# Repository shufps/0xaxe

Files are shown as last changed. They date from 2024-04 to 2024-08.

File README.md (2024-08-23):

**WARNING**: The 0xAxe is the *end level boss for Pros*. It's hard to get it working properly. The main reason is the powering scheme that uses 4 different voltage domain. It's difficult to get it into balance properly and needs very good and uniform cooling. The device works but can be super frustrating until it really is mining as it should. 

# 0xaxe

0xAxe is a 16-ASIC-BM1366 Miner based on the [QAxe](https://github.com/shufps/qaxe)



**rev1**: not tested</br>
**rev1.1**: working but needs some manual fixes</br>
**rev1.2**: should be working without fixes, but not tested yet.</br>

0xAxe is working (see screenshot at the end of the page to get an impression what to expect) 🥳

**note**: The 0xAxe is not a stand-alone device because it only supports USB but it can be run connected to a Raspberry Pi without problems. Also multiple devices can be connected to a single Pi. 

ASICs
=====

The 0xAxe uses 16 ASICs of type BM1366



Compilation (Bootloader or CMSIS-DAP)
======================================

```bash
# install curl
sudo apt install curl

# install rust
curl --proto '=https' --tlsv1.2 https://sh.rustup.rs -sSf | sh

# add to ~/.bash.rc (afterwards, opening a new terminal is needed)
echo 'source "$HOME/.cargo/env"' >> ~/.bashrc

# clone repository
git clone https://github.com/shufps/0xaxe

# clone submodules
cd 0xaxe
git submodule init
git submodule update

# add rust target for STM32L0 variants
rustup target add thumbv6m-none-eabi

# build firmware for L072
cd firmware/fw-L072KZ
./build.sh
```

Installation via USB Bootloader on board with `BOOT` button
===========================================================
The STM32L072CB variant has an integrated DFU Bootloader that starts when pressing the `BOOT` button during reset.

Afterwards the firmware can be flashed via `dfu-utils`:

```bash
# install cargo-binutils and llvm tools
cargo install cargo-binutils
rustup component add llvm-tools-preview

# create the firmware.bin
DEFMT_LOG=info cargo objcopy --release --bin qaxe -- -O binary 0xaxe.bin

# install dfu-utils
sudo apt-get install dfu-util

now start the stm32 in DFU mode by pressing `boot` 

# after booting, list the devices
dfu-util --list

# flash the binary
dfu-util -a 0 -s 0x08000000:leave -D 0xaxe.bin
```

Installation via CMSIS-DAP Programmer
=====================================

**note**: Using CMSIS-DAP and PicoProbe is only interesting for developers trying to alter the firmware.

As programming/debug adapter the Picoprobe firmware running on a Raspi Pico works best: <br>
https://github.com/rp-rs/rp2040-project-template/blob/main/debug_probes.md / https://github.com/raspberrypi/picoprobe/releases/tag/picoprobe-cmsis-v1.0.3
<br>
<br>
There also is a little board with only 3 parts that gives a nice low-cost solution to flash the Qaxe:<br>
https://github.com/shufps/raspi-pico-dap

On `rev3` there should be the option to boot the stm32 (by pressing the `boot`-button on reset) into DFU-Bootloader mode what makes flashing via USB and without CMSIS-DAP programmer possible.

## Flashing

After the source was compiled it is flashed by:

```bash
# build firmware for L072
cd firmware/fw-L072KZ
# run firmware (this also flashes it to the stm32)
./run.sh
```

Mining Client
=============



Stratum Mining Client:<br>
https://github.com/shufps/piaxe-miner

Misc
====
If you like this project and want to support future work, feel free to donate to: `bc1q29hp4fqtks2wzpmfwtpac64fnr8ujw2nvnra04`

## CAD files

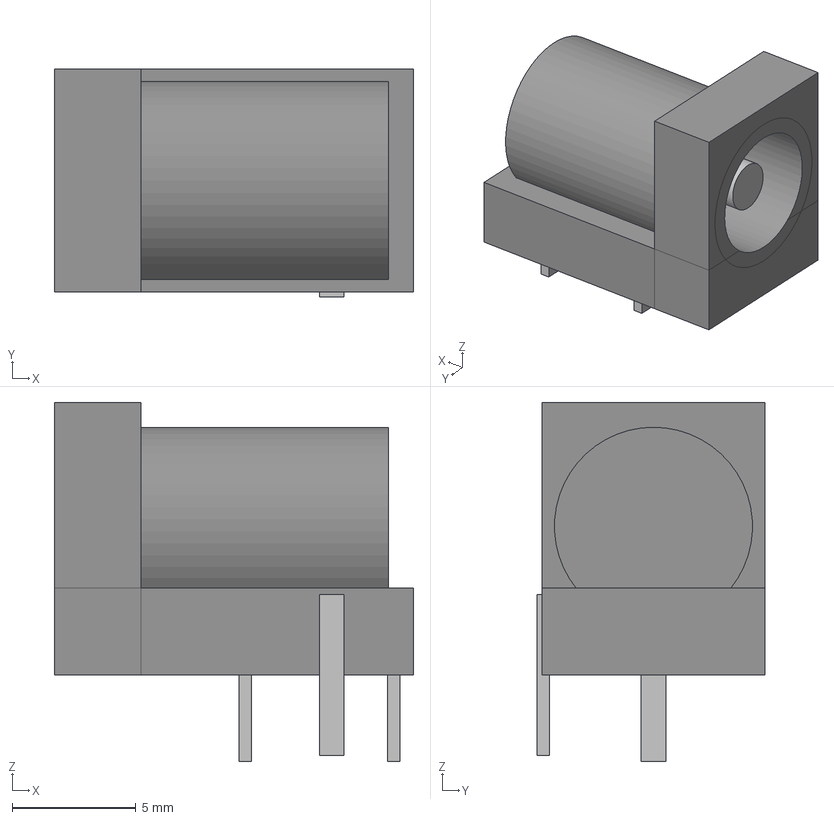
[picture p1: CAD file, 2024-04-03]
0xaxe/3d/barrel-jack.step
14.5 x 9.20 x 14.5 mm

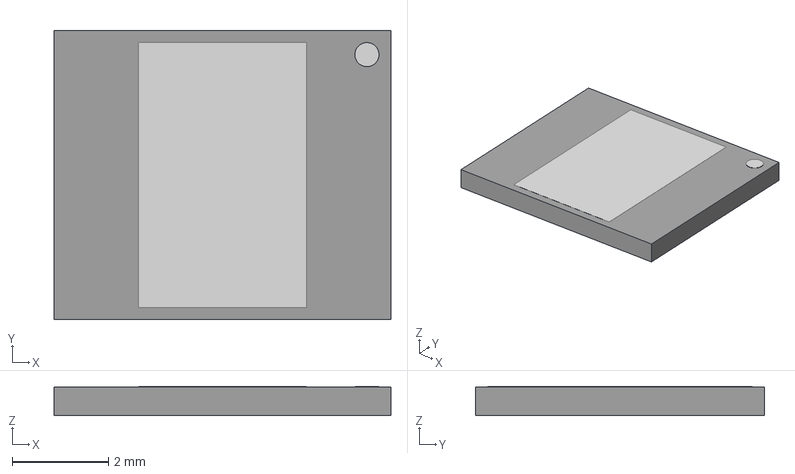
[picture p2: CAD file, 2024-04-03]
0xaxe/3d/bm1366.step
7.00 x 6.00 x 0.61 mm

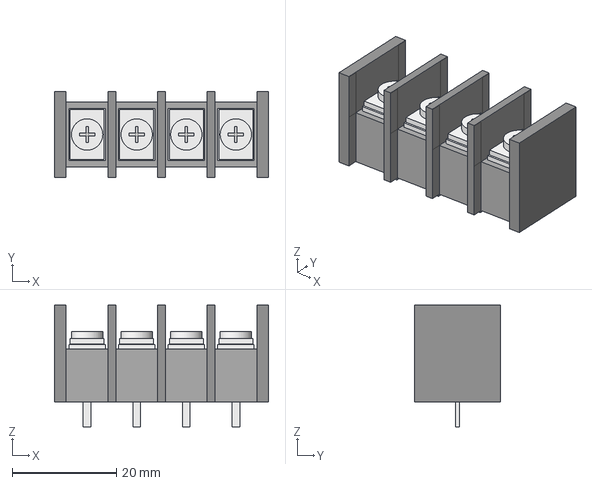
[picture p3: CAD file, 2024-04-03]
0xaxe/3d/4pin-connector.step
41.0 x 16.5 x 23.3 mm

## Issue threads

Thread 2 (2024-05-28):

A letter of BOM for Thomas Shufps

LuluLiu520, 2024-05-28:
Dear , Thomas Shufps

This is Lulu
Nice to meet you ：D
I downloaded the BOM info you provided from the website, but I realized that some of the info was missing.
Could you please confirm with me?
Attached is the missing BOM information.

Thank you for your help.
Best regards
[BOM with missing data.xlsx](https://github.com/shufps/0xaxe/files/15463017/BOM.with.missing.data.xlsx)

LuluLiu520, 2024-06-14:
I would very much like to do this program, I hope you can help me out, thank you.

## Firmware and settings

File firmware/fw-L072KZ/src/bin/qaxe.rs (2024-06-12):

#![no_std]
#![no_main]

use core::option::Option::Some;
use defmt::{panic, *};
use defmt_rtt as _; // global logger
use embassy_executor::Spawner;
use embassy_stm32::dma::NoDma;
use embassy_stm32::gpio::{Input, Level, Output, OutputType, Pull, Speed};
use embassy_stm32::i2c;
use embassy_stm32::i2c::I2c;
use embassy_stm32::rcc::*;
use embassy_stm32::time::{khz, Hertz};
use embassy_stm32::timer::simple_pwm::{PwmPin, SimplePwm};
use embassy_stm32::timer::Channel as PWMChannel;
use embassy_stm32::usart::BufferedUart;
use embassy_stm32::usb::{Driver, Instance};
use embassy_stm32::{bind_interrupts, peripherals, usart, usb, Config};
use embassy_sync::blocking_mutex::raw::{CriticalSectionRawMutex, ThreadModeRawMutex};
use embassy_sync::channel::Channel;
use embassy_sync::mutex::Mutex;
use embassy_sync::signal::Signal;
use embedded_io_async::Read;
use static_cell::StaticCell;
use embassy_time::{Delay, Timer};
use embassy_stm32::adc::{Adc, SampleTime};
use embassy_stm32::peripherals::ADC;
use embassy_stm32::adc;
use embassy_stm32::rcc::mux::Clk48sel;

use embassy_stm32::timer::OutputPolarity;
use embassy_usb::class::cdc_acm::{CdcAcmClass, State};
use embassy_usb::driver::EndpointError;
use embassy_usb::Builder;
use embedded_io_async::Write;
use futures::future::join5;
use panic_probe as _;

extern crate alloc;
extern crate alloc_cortex_m;

mod uid;

mod protobuf;
use protobuf::coms::{QControl, QRequest, QResponse, QState};
use quick_protobuf::{self, MessageWrite};

use alloc::borrow::Cow;

use alloc_cortex_m::CortexMHeap;

#[global_allocator]
static ALLOCATOR: CortexMHeap = CortexMHeap::empty();

bind_interrupts!(struct Irqs {
    USB => usb::InterruptHandler<peripherals::USB>;
    USART1 => usart::BufferedInterruptHandler<peripherals::USART1>;
    ADC1_COMP => adc::InterruptHandler<ADC>;
    I2C1 => i2c::EventInterruptHandler<peripherals::I2C1>, i2c::ErrorInterruptHandler<peripherals::I2C1>;
});
use embassy_stm32::peripherals::*;

#[derive(PartialEq)]
enum ResetManagerCommand {
    Reset,
}

#[derive(PartialEq)]
enum PowerManagerCommand {
    BuckOn,
    BuckOff,
}

//static RESET_MANAGER_SIGNAL: Signal<CriticalSectionRawMutex, ResetManagerCommand> = Signal::new();
static POWER_MANAGER_SIGNAL: Signal<CriticalSectionRawMutex, PowerManagerCommand> = Signal::new();

static AXE_CONTROL: Channel<ThreadModeRawMutex, Control, 1> = Channel::new();
static AXE_STATUS: Mutex<ThreadModeRawMutex, Status> = Mutex::new(Status {
    power_enabled: false,
    temp: [0i32; 4],
    domain: [0i32; 4],
});

#[derive(Clone, Copy)]
struct Control {
    led2: bool,
    pwm: [i32; 4],
}

#[derive(Clone, Copy)]
struct Status {
    power_enabled: bool,
    temp: [i32; 4],
    domain: [i32; 4],
}

impl From<Status> for QState {
    fn from(value: Status) -> Self {
        QState {
            pgood_1v2: 0,
            power_enabled: if value.power_enabled { 1 } else { 0 },
            temp1: value.temp[0],
            temp2: value.temp[1],
            temp3: value.temp[2],
            temp4: value.temp[3],
            domain1: value.domain[0],
            domain2: value.domain[1],
            domain3: value.domain[2],
            domain4: value.domain[3],
        }
    }
}

impl From<QControl> for Control {
    fn from(value: QControl) -> Self {
        Control {
            led2: value.led2 == 1,
            pwm: [value.pwm1, value.pwm2, value.pwm3, value.pwm4],
        }
    }
}

#[embassy_executor::main]
async fn main(spawner: Spawner) {
    info!("Hello World!");

    // Initialize the allocator before using it
    let start = cortex_m_rt::heap_start() as usize;
    let size = 1024;
    unsafe { ALLOCATOR.init(start, size) }

    let mut config = Config::default();
    config.rcc.hsi48 = Some(Hsi48Config {
        sync_from_usb: true,
    }); // needed for USB
    config.rcc.sys = Sysclk::PLL1_R;
    config.rcc.hsi = true;
    config.rcc.pll = Some(Pll {
        source: PllSource::HSI,
        div: PllDiv::DIV3,
        mul: PllMul::MUL6,
    });
    config.rcc.mux.clk48sel = Clk48sel::HSI48;

    let p = embassy_stm32::init(config);

    let driver = Driver::new(p.USB, Irqs, p.PA12, p.PA11);

    // Create embassy-usb Config
    let mut config = embassy_usb::Config::new(0xc0de, 0xcafe);
    config.max_packet_size_0 = 64;
    config.manufacturer = Some("microengineer");
    config.product = Some("0xAxe");
    config.serial_number = Some(uid::uid_hex());

    // Required for windows compatibility.
    // https://developer.nordicsemi.com/nRF_Connect_SDK/doc/1.9.1/kconfig/CONFIG_CDC_ACM_IAD.html#help
    config.device_class = 0xEF;
    config.device_sub_class = 0x02;
    config.device_protocol = 0x01;
    config.composite_with_iads = true;

    // Create embassy-usb DeviceBuilder using the driver and config.
    // It needs some buffers for building the descriptors.
    let mut device_descriptor = [0; 256];
    let mut config_descriptor = [0; 256];
    let mut bos_descriptor = [0; 256];
    let mut control_buf = [0; 64];

    let mut state_usb_asic = State::new();
    let mut state_usb_ctrl = State::new();

    let mut builder = Builder::new(
        driver,
        config,
        &mut device_descriptor,
        &mut config_descriptor,
        &mut bos_descriptor,
        &mut [], // no msos descriptors
        &mut control_buf,
    );

    // Create classes on the builder.
    let class_usb_asic = CdcAcmClass::new(&mut builder, &mut state_usb_asic, 64);
    let (mut sender, mut receiver) = class_usb_asic.split();

    let mut class_usb_ctrl = CdcAcmClass::new(&mut builder, &mut state_usb_ctrl, 64);

    // Build the builder.
    let mut usb = builder.build();

    let mut config = usart::Config::default();
    config.baudrate = 115200;

    static TX_BUF: StaticCell<[u8; 256]> = StaticCell::new();
    let tx_buf = &mut TX_BUF.init([0; 256])[..];
    static RX_BUF: StaticCell<[u8; 256]> = StaticCell::new();
    let rx_buf = &mut RX_BUF.init([0; 256])[..];

    let usart = BufferedUart::new(p.USART1, Irqs, p.PA10, p.PA9, tx_buf, rx_buf, config).unwrap();
    let (mut tx_ctrl, mut rx_ctrl) = usart.split();

    // Run the USB device.
    let usb_fut = usb.run();

    let pwr_en = Output::new(p.PB1, Level::Low, Speed::Low);
    let pwr_sdn = Output::new(p.PB0, Level::High, Speed::Low);
    let pwr_enabled = Input::new(p.PC14, Pull::None);
    let pgood_led = Output::new(p.PA6, Level::High, Speed::Low);
    let led2 = Output::new(p.PA7, Level::High, Speed::Low);

    let reset = Output::new(p.PA8, Level::Low, Speed::Low);

    let ch2 = PwmPin::new_ch2(p.PB3, OutputType::PushPull);
    let mut pwm1 = SimplePwm::new(
        p.TIM2,
        None,
        Some(ch2),
        None,
        None,
        khz(10),
        Default::default(),
    );
    pwm1.set_polarity(PWMChannel::Ch2, OutputPolarity::ActiveHigh);
    pwm1.set_duty(PWMChannel::Ch2, pwm1.get_max_duty() / 2);
    pwm1.enable(PWMChannel::Ch2);

    let i2c = I2c::new(
        p.I2C1,
        p.PB6,
        p.PB7,
        Irqs,
        NoDma,
        NoDma,
        Hertz(100_000),
        Default::default(),
    );

    let mut adc = Adc::new(p.ADC, Irqs, &mut Delay);
    adc.set_sample_time(SampleTime::CYCLES160_5);

    let mut vrefint = adc.enable_vref(&mut Delay);
    let mut adc_pin_domain1 = p.PA0;
    let mut adc_pin_domain2 = p.PA1;
    let mut adc_pin_domain3 = p.PA2;
    let mut adc_pin_domain4 = p.PA3;

    let vrefint_sample = adc.read(&mut vrefint).await;

    let convert_to_millivolts = |sample| {
        // From https://www.st.com/resource/en/datasheet/stm32l051c6.pdf
        // 6.3.3 Embedded internal reference voltage
        const VREFINT_MV: u32 = 1224; // mV

        (u32::from(sample) * VREFINT_MV / u32::from(vrefint_sample)) as u16
    };

    let adc_fut = async {
        loop {
            let mut samples = [0u16; 4];
            for (i, sample) in samples.iter_mut().enumerate().take(4) {
                let value = match i {
                    0 => adc.read(&mut adc_pin_domain1).await,
                    1 => adc.read(&mut adc_pin_domain2).await,
                    2 => adc.read(&mut adc_pin_domain3).await,
                    3 => adc.read(&mut adc_pin_domain4).await,
                    _ => 0,
                };
                *sample = convert_to_millivolts(value);
            }
            let mut state = AXE_STATUS.lock().await;
            state.domain[0] = samples[0] as i32;
            state.domain[1] = samples[1] as i32;
            state.domain[2] = samples[2] as i32;
            state.domain[3] = samples[3] as i32;
            drop(state);
            info!("adc values: domain1={}, domain2={}, domain3={}, domain4={}", samples[0], samples[1], samples[2], samples[3]);
            Timer::after_millis(1000).await;
        }
    };

//    unwrap!(spawner.spawn(reset_manager(reset)));
    unwrap!(spawner.spawn(power_manager(pwr_en, pwr_sdn, reset)));
    unwrap!(spawner.spawn(power_good_task(pwr_enabled, pgood_led)));
    unwrap!(spawner.spawn(axe_control_channel(pwm1, led2)));
    unwrap!(spawner.spawn(temp_manager(i2c)));

    let protobuf_rpc_fut = async {
        loop {
            class_usb_ctrl.wait_connection().await;
            info!("Connected");
            let _ = protobuf_rpc(&mut class_usb_ctrl).await;
            info!("Disconnected");
        }
    };

    let relay_receiver_fut = async {
        loop {
            let mut usb_buf = [0; 64];
            receiver.wait_connection().await;
            info!("Connected relay receiver");

            loop {
                let usb_read = match receiver.read_packet(&mut usb_buf).await {
                    Ok(n) => n,
                    Err(e) => {
                        error!("Error reading from USB: {:?}", e);
                        break;
                    }
                };

                if usb_read == 0 {
                    continue; // No data read, continue the loop
                }

                debug!("USB -> USART: {:x}", &usb_buf[..usb_read]);

                if let Err(e) = tx_ctrl.write_all(&usb_buf[..usb_read]).await {
                    error!("Error writing to USART: {:?}", e);
                    break;
                }
            }
        }
    };

    let relay_sender_fut = async {
        loop {
            sender.wait_connection().await;

            info!("Connected relay sender");

            let mut toggle = 0;
            let mut num_bytes = 0;
            let mut received = [0u8; 11];
            let preample = [0xaa, 0x55];
            loop {
                let mut byte = [0u8; 1];
                match rx_ctrl.read_exact(&mut byte).await {
                    Ok(_) => (),
                    Err(e) => {
                        error!("Error reading from USART: {:?}", e);
                    }
                };

                received[num_bytes] = byte[0];

                // try to sync on serial data
                match num_bytes {
                    0 | 1 =>
                    // wait for 0xaa 0x55
                    {
                        if received[num_bytes] != preample[num_bytes] {
                            debug!("unexpected start of serial data, trying to resync ...");
                            num_bytes = 0;
                            continue;
                        }
                    }
                    _ => {}
                };

                num_bytes += 1;

                if num_bytes != 11 {
                    continue;
                }
                num_bytes = 0;
                /*
                                // toggle led with each response received
                                toggle = 1 - toggle;
                                match toggle {
                                    0 => activity_led.set_high(),
                                    1 => activity_led.set_low(),
                                    _ => {}
                                };
                */
                debug!("USART -> USB: {:x}", &received[..]);
                if let Err(e) = sender.write_packet(&received[..]).await {
                    error!("Error writing to USB: {:?}", e);
                    break;
                }
            }
        }
    };

    let _ = join5(
        usb_fut,
        protobuf_rpc_fut,
        relay_receiver_fut,
        relay_sender_fut,
        adc_fut,
    )
    .await;
}

#[embassy_executor::task]
async fn power_good_task(power_enabled: Input<'static>, mut pgood_led: Output<'static>) {
    loop {
        let mut state = AXE_STATUS.lock().await;

        if power_enabled.is_high() {
            state.power_enabled = true;
            pgood_led.set_low();
        } else {
            state.power_enabled = false;
            pgood_led.set_high();
        }
        drop(state);
        Timer::after_millis(500).await;
    }
}
#[embassy_executor::task]
async fn power_manager(mut pwr_en: Output<'static>, mut pwr_sdn: Output<'static>, mut reset: Output<'static>) {
    loop {
        let signal = POWER_MANAGER_SIGNAL.wait().await;

        if signal == PowerManagerCommand::BuckOn {
            info!("switching buck on");
            // disable shutdown and set reset
            pwr_sdn.set_low();
            reset.set_low();
            Timer::after_millis(100).await;
            // pulse pwr_en
            pwr_en.set_high();
            Timer::after_millis(100).await;
            pwr_en.set_low();
            Timer::after_millis(1000).await;
            // release reset
            reset.set_high();
        }

        if signal == PowerManagerCommand::BuckOff {
            info!("switching buck off");
            pwr_sdn.set_high();
            Timer::after_millis(10).await;
        }
        POWER_MANAGER_SIGNAL.reset();
    }
}
/*
#[embassy_executor::task]
async fn reset_manager(mut reset: Output<'static>) {
    loop {
        let signal = RESET_MANAGER_SIGNAL.wait().await;

        if signal != ResetManagerCommand::Reset {
            continue;
        }

        info!("reset triggered!");
        reset.set_low();
        Timer::after_millis(100).await;
        reset.set_high();
    }
}
*/
#[embassy_executor::task]
async fn axe_control_channel(mut pwm1: SimplePwm<'static, TIM2>, mut led2: Output<'static>) {
    loop {
        let control = AXE_CONTROL.receive().await;

        for i in 0..4 {
            match i {
                0 => {
                    let max_duty = pwm1.get_max_duty() as u32;
                    let duty = max_duty * control.pwm[i] as u32 / 100;
                    info!("pwm{}: {}, max: {}", i, duty, max_duty);
                    pwm1.set_duty(
                        PWMChannel::Ch2,
                        if duty <= max_duty {
                            duty as u16
                        } else {
                            max_duty as u16
                        },
                    );
                }
                _ => { /* NOP */ }
            };
        }
        if control.led2 {
            led2.set_low();
        } else {
            led2.set_high();
        }

        Timer::after_millis(500).await;
    }
}
struct Disconnected {}

impl From<EndpointError> for Disconnected {
    fn from(val: EndpointError) -> Self {
        match val {
            EndpointError::BufferOverflow => panic!("Buffer overflow"),
            EndpointError::Disabled => Disconnected {},
        }
    }
}

enum Errors {
    None = 0,
    InvalidCommand = 1,
    ErrorDeserializingRequest = 2,
    ErrorSerializingResponse = 3,
    ErrorDeserializingRequestData = 4,
    ErrorSerializingResponseData = 5,
}

impl Errors {
    fn to_string(error: &Errors) -> &'static str {
        match error {
            Errors::InvalidCommand => "invalid command",
            Errors::ErrorDeserializingRequest => "error deserializing request",
            Errors::ErrorSerializingResponse => "error serializing response",
            Errors::ErrorDeserializingRequestData => "error deserializing request data",
            Errors::ErrorSerializingResponseData => "error serializing response data",
            _ => "unknown error",
        }
    }
}
enum Commands {
    NOP = 0,
    Control = 1,
    Status = 2,
    Reset = 3,
    Shutdown = 4,
    PowerOn = 5,
}

impl Commands {
    fn from_i32(value: i32) -> Option<Commands> {
        match value {
            0 => Some(Commands::NOP),
            1 => Some(Commands::Control),
            2 => Some(Commands::Status),
            3 => Some(Commands::Reset),
            4 => Some(Commands::Shutdown),
            5 => Some(Commands::PowerOn),
            _ => None,
        }
    }
}

impl QResponse<'_> {
    fn default() -> QResponse<'static> {
        QResponse {
            id: 0,
            error: 0,
            data: Cow::Borrowed(&[0u8]),
        }
    }
}

// The response_bytes should be a mutable slice of u8, not a slice of a mutable slice.
async fn process_request<'a>(
    request: &QRequest<'_>,
    response: &mut QResponse<'_>,
) -> Result<usize, Errors> {
    let mut response_data = [0u8; 32];
    let mut response_len = 0;
    let error = Errors::None as i32;

    let op = Commands::from_i32(request.op);
    if op.is_none() {
        return Err(Errors::InvalidCommand);
    }

    match op.unwrap() {
        Commands::NOP => {
            // nop
        }
        Commands::Control => {
            let cmd: QControl = quick_protobuf::deserialize_from_slice(&request.data)
                .map_err(|_| Errors::ErrorDeserializingRequestData)?;

            info!(
                "received ctrl command with parameters led2: {}, pwm1: {}, pwm2: {}, pwm3: {}, pwm4: {}",
                cmd.led2, cmd.pwm1, cmd.pwm2, cmd.pwm3, cmd.pwm4
            );

            AXE_CONTROL.send(Control::from(cmd)).await;
        }
        Commands::Status => {
            info!("status");
            let xstate = AXE_STATUS.lock().await;
            let state = QState::from(*xstate);
            drop(xstate);

            response_len = state.get_size() + 1 /* varint */;

            debug!("response-len: {}", response_len);

            quick_protobuf::serialize_into_slice(&state, &mut response_data[..])
                .map_err(|_| Errors::ErrorSerializingResponseData)?;
        }
        Commands::Reset => {}, //RESET_MANAGER_SIGNAL.signal(ResetManagerCommand::Reset),
        Commands::Shutdown => POWER_MANAGER_SIGNAL.signal(PowerManagerCommand::BuckOff),
        Commands::PowerOn => POWER_MANAGER_SIGNAL.signal(PowerManagerCommand::BuckOn),
    };

    response.id = request.id;
    response.error = error;
    response.data = Cow::Owned(response_data[..response_len].to_vec());
    debug!(
        "response.id: {}, response.error:{}, response.data: {:?}",
        response.id,
        response.error,
        response_data[..response_len]
    );
    Ok(response_len)
}

async fn protobuf_rpc<'d, T: Instance + 'd>(
    class: &mut CdcAcmClass<'d, Driver<'d, T>>,
) -> Result<(), Disconnected> {
    let mut request_bytes = [0u8; 64];
    let mut response_bytes = [0u8; 64];

    loop {
        let n = class.read_packet(&mut request_bytes).await?;

        let mut response = QResponse::default();

        let request = match quick_protobuf::deserialize_from_slice(&request_bytes[..n]) {
            Ok(req) => Some(req),
            Err(_) => {
                error!("{}", Errors::to_string(&Errors::ErrorDeserializingRequest));
                response = QResponse::default();
                response.error = Errors::ErrorDeserializingRequest as i32;
                None
            }
        };

        // if request is some then we can process the request
        if request.is_some() {
            if let Err(e) = process_request(&request.unwrap(), &mut response).await {
                error!("{}", Errors::to_string(&e));
                response = QResponse::default();
                response.error = e as i32;
            }
        }

        let serialized_len = response.get_size() + 1 /* varint */;
        if quick_protobuf::serialize_into_slice(&response, &mut response_bytes).is_err() {
            error!("{}", Errors::to_string(&Errors::ErrorSerializingResponse));
            continue;
        }

        class
            .write_packet(&response_bytes[..serialized_len])
            .await?;
    }
}

#[embassy_executor::task]
async fn temp_manager(mut i2c: I2c<'static, I2C1>) {
    loop {
        for i in 0..2 {
            let mut data = [0u8; 2];
            if let Err(e) = i2c.blocking_read(0x48 + i, &mut data) {
                error!("i2c error: {:?}", e);
                continue;
            }

            let mut temp_data = ((data[0] as u16) << 4) | ((data[1] as u16) >> 4);

            if temp_data > 2047 {
                temp_data -= 4096
            }

            info!("read temp{}: {}", i, temp_data);

            let mut state = AXE_STATUS.lock().await;
            state.temp[i as usize] = temp_data as i32;
            drop(state);
        }

        Timer::after_millis(5000).await;
    }
}

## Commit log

2024-04-03 renamed file
    [flex.kicad_sch, flex2.kicad_sch]
2024-04-03 reference designators silkscreen top and bottom
    [0xaxe-B_Cu.gbl, 0xaxe-B_Mask.gbs, 0xaxe-B_Paste.gbp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]
2024-04-03 digikey bom
    [digikey.csv]
2024-04-20 added two extra mounting holes
    [0xaxe-B_Cu.gbl, 0xaxe-B_Mask.gbs, 0xaxe-B_Paste.gbp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]
2024-04-20 2nd new mounting hole was slightly off
    [0xaxe-B_Cu.gbl, 0xaxe-B_Mask.gbs, 0xaxe-B_Paste.gbp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]
